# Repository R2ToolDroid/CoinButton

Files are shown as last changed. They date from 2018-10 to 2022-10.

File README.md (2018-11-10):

# CoinButton
CoinButton as input Terminal

### Here you find my R2 ToolDroid Project COIN BUTTON SYSTEM ###

Use your droids Coin Buttons as command send buttons

These Panel based on following Parts:

- Arduino Nano
- PCB - CoinButton Board (actual prototype, new one comming soon)
- Script
- 3D printet Coinbuttons 
- 3D printet Frame for PCB and Buttons
- 3D Clips to hold the PCB to Frame

The Panel sends 17 configurable commands via Serial out TX Port on the Arduino Nano

The actual Script include some Marcduino Commands for the Dome Boards but you can easy customize.

https://www.youtube.com/watch?v=c4UOg3DOG3U

Have fun...

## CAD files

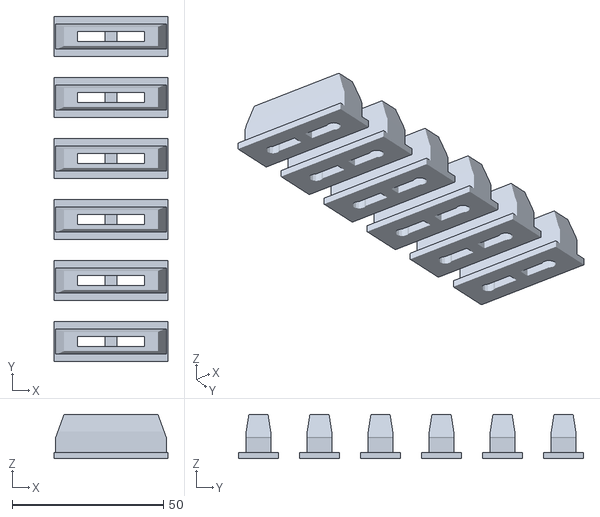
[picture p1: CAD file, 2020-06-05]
0088-02-r2-coin-buttons-panelmot.stl
37.6 x 114.2 x 14.7

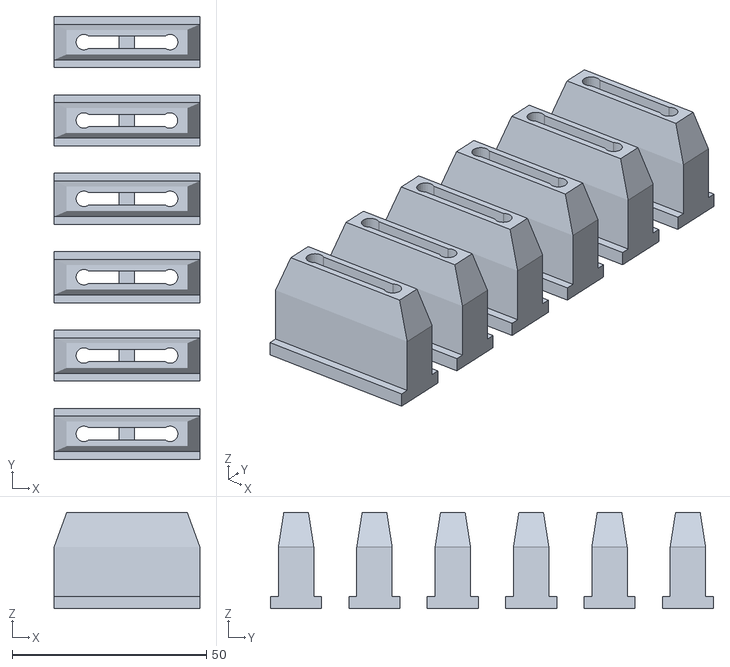
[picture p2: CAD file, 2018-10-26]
0088-r2-coin-buttons-panelmot.stl
37.6 x 114.2 x 24.8

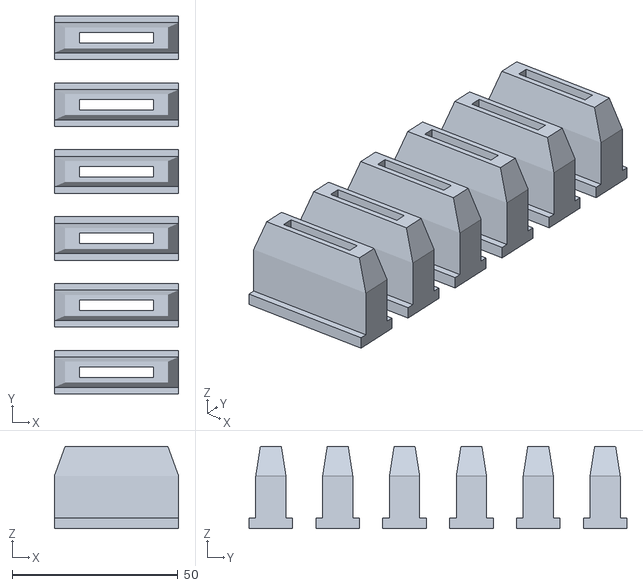
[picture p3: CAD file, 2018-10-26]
0088-r2-coin-buttons.stl
37.6 x 114.2 x 24.8

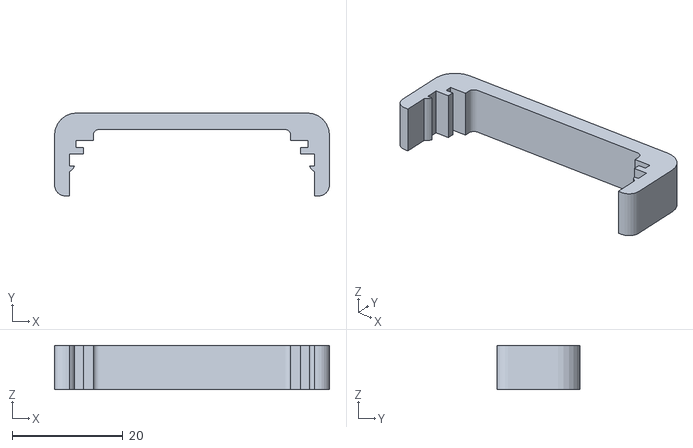
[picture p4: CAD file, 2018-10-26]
0087-r2-coin-clip.stl
49.6 x 15.0 x 8.00

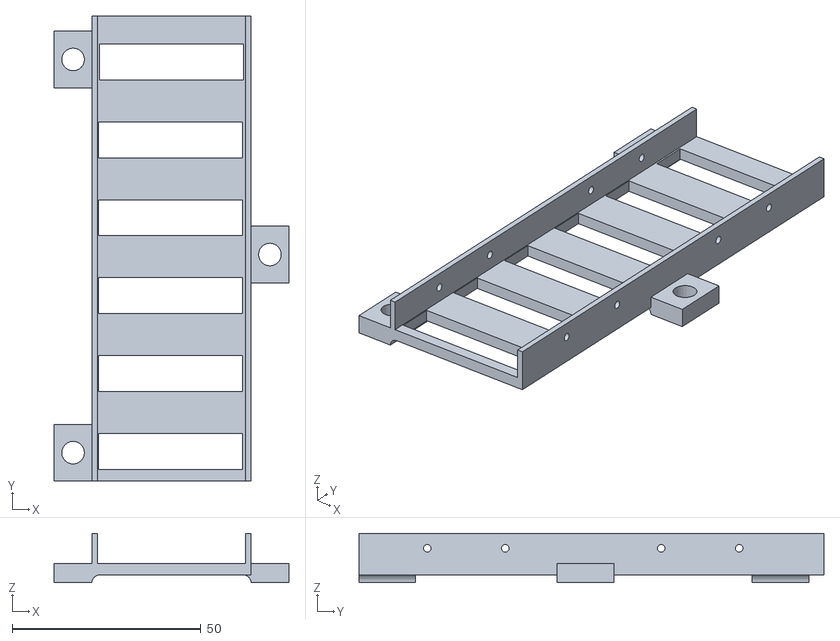
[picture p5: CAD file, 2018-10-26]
0087-r2-coin-button-frame.stl
62.1 x 123.1 x 13.0

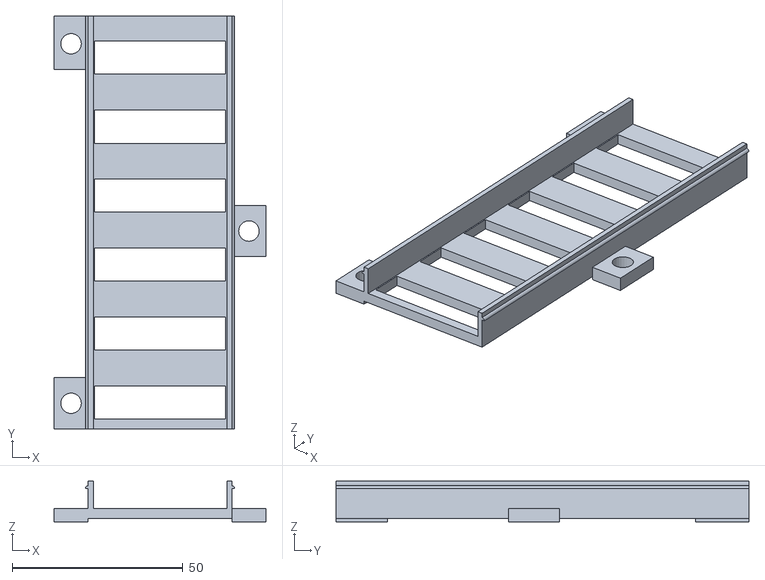
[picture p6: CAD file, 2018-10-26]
0087-r2-coin-button-frame-rev1.stl
62.1 x 120.8 x 12.0

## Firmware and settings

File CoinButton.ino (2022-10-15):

/*
  CoinButton Taster System R2 ToolDroid
  created 2018
  by Doc Snyder <https://github.com/R2ToolDroid>

  System mit Serial Read Input
*/

// constants won't change. They're used here to
// set pin numbers:

//    A                        B
//  LED 7   A0-14   |  Button 1   |   LED 1    D13-13
//  LED 8   A1-15   |  Button 2   |   LED 2    D12-12
//  LED 9   A2-16   |  Button 3   |   LED 3    D11-11
//  LED 10  A3-17   |  Button 4   |   LED 4    D10-10
//  LED 11  A4-18   |  Button 5   |   LED 5    D9-9
//  LED 12  D8-8    |  Button 6   |   LED 6    A5-19


//Button 5 and 6 are for select Level
//Button 4 is for Excecute the Command
//HOLD BUTTON 5 on Start for Debugsequence

//Arduino Pin Numbers V3 

// TX - 1  
// RX - 0  
// D2 - 2
// D3 - 3
// D4 - 4
// D5 - 5
// D6 - 6
// D7 - 7
// D8 - 8
// D9 - 9
// D10- 10
// D11- 11
// D12- 12
// D13- 13

// A0 - 14
// A1 - 15
// A2 - 16
// A3 - 17
// A4 - 18
// A5 - 19
// A6 - 20 ?
// A7 - 21 ?

int buttonPin[] = {7, 6, 5, 4, 3, 2};     // Button PIN Array
int ledPinA[] =  {14, 15, 16, 17, 18, 8};      // the number of the LED pin
int ledPinB[] =  {13, 12, 11, 10, 9, 19};      // the number of the LED pin

int pinCount = 6; //Raster 6 Tasten
int level = 0;

// this String will come in future from SD Card to make R2 easyer to learn
// this Sting shuld have 17 Commands now
// Here typical Marcduino Commands
// Direkt push Commands:
// BUTTON 1   Reset and mode0 RAND to Dome
// BUTTON 2   mode1 RC to Dome
// BUTTON 3   charge panel open
// BUTTON 4   EXECUTE Sequence
// BUTTON 5   Level +
// BUTTON 6   Level -



String syscmd[] = {
  "CB0",      //0   Close all panels (full speed), servo off - use as init only. Use CL00 for all soft close.
  "CB1",      //1   Scream, with all panels open
  "CB2",      //2   
  "CB3",      //3   
  "CB4",      //4   Wave 2 (open progressively all panels, then close one by one)
  "CB5",      //5   Beep Cantina (with marching ants panel action)
  "CB6",     //6   Faint/Short Circuit
  "CB7",      //7   Cantina dance (orchestral, rhythmic panel dance)
  "CB8",      //8   Leia
  "CB9",      //9   Disco
  "CB10",      //10  Quite Mode reset (panel close, stop holos, stop sounds)
  "CB11",      //11  Full Awake Mode reset (panel close, random sound, holo movement, no holo lights)
  "CB12",      //12  Top Panels to RC
  "CB13",      //13    Mid Awake Mode reset (panel close, random sound, stop holos)
  "CB14",      //14  Awake+ Mode reset ((panel close, random sound, holo movement, lights on)
  "CB15",     //15
  "CB16",       //16
  "CB17"       //17
  

};

// Vars for Serial Input

String cmd; //Consohlen Input

// variables will change:

int buttonState1 = 0;         // variable for reading the pushbutton status
int buttonState2 = 0;         // variable for reading the pushbutton status
int buttonState3 = 0;
int buttonState4 = 0;
int buttonState5 = 0;
int buttonState6 = 0;

int debug = 0; //Debug function

void setup() {
  Serial.begin(9600);

  // set the pin as Input and Output:
  for (int thisPin = 0; thisPin < pinCount; thisPin++) {
    pinMode(ledPinA[thisPin], OUTPUT);
    pinMode(ledPinB[thisPin], OUTPUT);
    pinMode(buttonPin[thisPin], INPUT);
  }
  
  if (digitalRead(buttonPin[5]) == HIGH) {

  Serial.println("SCRIPT: CoinButton 13.10.2020");
  Serial.println("initiate......");
  Serial.println("DebugMode ON");
  Serial.println("...");
  delay(5000);
  debug = 1;
  }
}



void loop() {

  

  // read the state of the pushbutton value:
  buttonState1 = digitalRead(buttonPin[0]);
  buttonState2 = digitalRead(buttonPin[1]);
  buttonState3 = digitalRead(buttonPin[2]);
  buttonState4 = digitalRead(buttonPin[3]);
  buttonState5 = digitalRead(buttonPin[4]);
  buttonState6 = digitalRead(buttonPin[5]);

  //if (level >= 0 ) {
  //    digitalWrite(ledPinA[level], HIGH);
  //   digitalWrite(ledPinB[level], HIGH);
  //   }

  matrix();
  if (debug == 1) {
    Serial.print("LEVEL= ");
    Serial.println(level);
  }

  // check if the pushbutton is pressed.
  // if it is, the buttonState is HIGH:
  if (buttonState1 == HIGH) {

    if (debug == 1) {
    Serial.println("Button-1 - Levelreset");
    }

    Serial.print("CBD1");
    Serial.print("\n");
    delay(1000);
    
    level = 0;
    
      for (int thisPin = 0; thisPin < pinCount; thisPin++) {
        digitalWrite(ledPinA[thisPin], HIGH);
        digitalWrite(ledPinB[thisPin], HIGH);
        
        buttonState2 == LOW;
        buttonState3 == LOW;
        
        
        } 
  }// end button 1
  
      for (int thisPin = 0; thisPin < pinCount; thisPin++) {
           digitalWrite(ledPinA[thisPin], LOW);
          digitalWrite(ledPinB[thisPin], LOW);
        }   // end for
    
    

  if (buttonState2 == HIGH) {
    
    if (debug == 1) {
      Serial.println("Button-2");
    }

    for (int thisPin = 0; thisPin < pinCount; thisPin++) {
      digitalWrite(ledPinA[thisPin], HIGH);
      digitalWrite(ledPinB[thisPin], HIGH);
    }
    
    Serial.print ("CBD2");
    Serial.print ("\n");

    delay(1000);

   
    
    buttonState2 == LOW;
    
    for (int thisPin = 0; thisPin < pinCount; thisPin++) {
      digitalWrite(ledPinA[thisPin], LOW);

      digitalWrite(ledPinB[thisPin], LOW);
      delay(100);
    }
 } 

  if (buttonState3 == HIGH) {
    // turn LED on:

    if (debug == 1) {
      Serial.println("Button-3");
    }

    Serial.print ("CBD3");
    Serial.print ("\n");
    delay(1000);

    
    for (int thisPin = 0; thisPin < pinCount; thisPin++) {
      digitalWrite(ledPinA[thisPin], LOW);
      digitalWrite(ledPinB[thisPin], LOW);
    }

  } else {
    // turn LED off:

  }

  if (buttonState4 == HIGH) {
    // turn LED on:

    if (debug == 1) {
      Serial.println("Button-4");
    }
   
    ///Hier Befehl ausführen
    if (debug == 1) {
    Serial.print("LEVEL= ");
    Serial.print(level);
    Serial.print (" ...Execute");
    Serial.print("\n");
    }

     Serial.print(syscmd[level]);
     Serial.print("\n");
    
    for (int thisPin = 0; thisPin < pinCount; thisPin++) {
      digitalWrite(ledPinA[thisPin], HIGH);

      digitalWrite(ledPinB[thisPin], HIGH);
      delay (100);
    }

    for (int thisPin = 0; thisPin < pinCount; thisPin++) {
      digitalWrite(ledPinA[thisPin], LOW);

      digitalWrite(ledPinB[thisPin], LOW);
      delay(100);
    }


  } else {
    // turn LED off:

  }


  if (buttonState5 == HIGH) {
    // turn LED on:
    if (debug == 1) {
      Serial.println("Button-5");
    }
    //digitalWrite(ledPinA6 HIGH);

    if (level >= 0 && level <= 17) {
      level--;
    }
    delay(200);


  }


  if (buttonState6 == HIGH) {
    // turn LED on:
    if (debug == 1) {
      Serial.println("Button-6");
    }
    if (level >= -1 && level <= 16) {

      level++;
    }
    delay(200);


  }

   getCMD();
}



void getCMD() {     // Input Comando auswerten
  
  while(Serial.available() > 0  ) {
    
        cmd= Serial.readString();// read the incoming data as string
        Serial.println(cmd); 

        if (cmd)
        {
          level = cmd.toInt();
        }

        
     
    } // End While
  
}

int matrix() {

  switch (level) {
    case 0:
      digitalWrite(ledPinA[level], HIGH);
      digitalWrite(ledPinB[level], HIGH);
      break;
    case 1:
      digitalWrite(ledPinA[level], HIGH);
      digitalWrite(ledPinB[level], HIGH);
      break;

    case 2:
      digitalWrite(ledPinA[level], HIGH);
      digitalWrite(ledPinB[level], HIGH);
      break;
    case 3:
      digitalWrite(ledPinA[level], HIGH);
      digitalWrite(ledPinB[level], HIGH);
      break;
    case 4:
      digitalWrite(ledPinA[level], HIGH);
      digitalWrite(ledPinB[level], HIGH);
      break;

    case 5:
      digitalWrite(ledPinA[level], HIGH);
      digitalWrite(ledPinB[level], HIGH);
      break;

    case 6:
      digitalWrite(ledPinA[0], HIGH);
      break;
    case 7:
      digitalWrite(ledPinB[0], HIGH);
      break;
    case 8:
      digitalWrite(ledPinA[1], HIGH);
      break;
    case 9:
      digitalWrite(ledPinB[1], HIGH);
      break;
    case 10:
      digitalWrite(ledPinA[2], HIGH);
      break;
    case 11:
      digitalWrite(ledPinB[2], HIGH);
      break;
    case 12:
      digitalWrite(ledPinA[3], HIGH);
      break;
    case 13:
      digitalWrite(ledPinB[3], HIGH);
      break;
    case 14:
      digitalWrite(ledPinA[4], HIGH);
      break;
    case 15:
      digitalWrite(ledPinB[4], HIGH);
      break;
    case 16:
      digitalWrite(ledPinA[5], HIGH);
      break;
    case 17:
      digitalWrite(ledPinB[5], HIGH);
      break;

  }


}

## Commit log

2018-11-17 Update for new PCB Designtest
    Pins are changed. Debug will start when hold button 6 on fireup
2018-12-19 After first live Test
    fix some issues and set some new command
    [CoinButton.ino]
2018-12-21 Levlel Commands new
    Switch level Commands direct do Mastercontroller for better maintinance
2018-12-22 Update
    fix some issues
    [CoinButton.ino]
2018-12-25 Fix Issus
    Fix CH16 space
    [CoinButton.ino]
2019-03-13 fix byte for Debug
    change declaration to int
    [CoinButton.ino]
2019-08-02 new GerberFiles
    Tested PCB Files
2020-06-05 Smaller Buttons for better push feeling
    [0088-02-r2-coin-buttons-panelmot.ipt]
2020-06-05 Small one for better feeling
    [0088-02-r2-coin-buttons-panelmot.stl]
2022-10-15 Remove PrintLN
    Line 252 prinln and /n are double
    Fix system fail on CB commands
    [CoinButton.ino]
